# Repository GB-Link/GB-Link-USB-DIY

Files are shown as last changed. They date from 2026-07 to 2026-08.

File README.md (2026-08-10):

# GB-Link USB DIY: USB TO GAME BOY LINK ADAPTER

Board 3D Render

An Open-Source USB to Gameboy Link Cable Adapter for Raspberry Pi Pico. Designed with components that are easy to source and solder. Original design by agtbaskara. Link port footprint added by fairy0715. 
This board allows you to connect to GB/C or GBA games using a gereric GBC cable. OEM cables will work with their expected games.

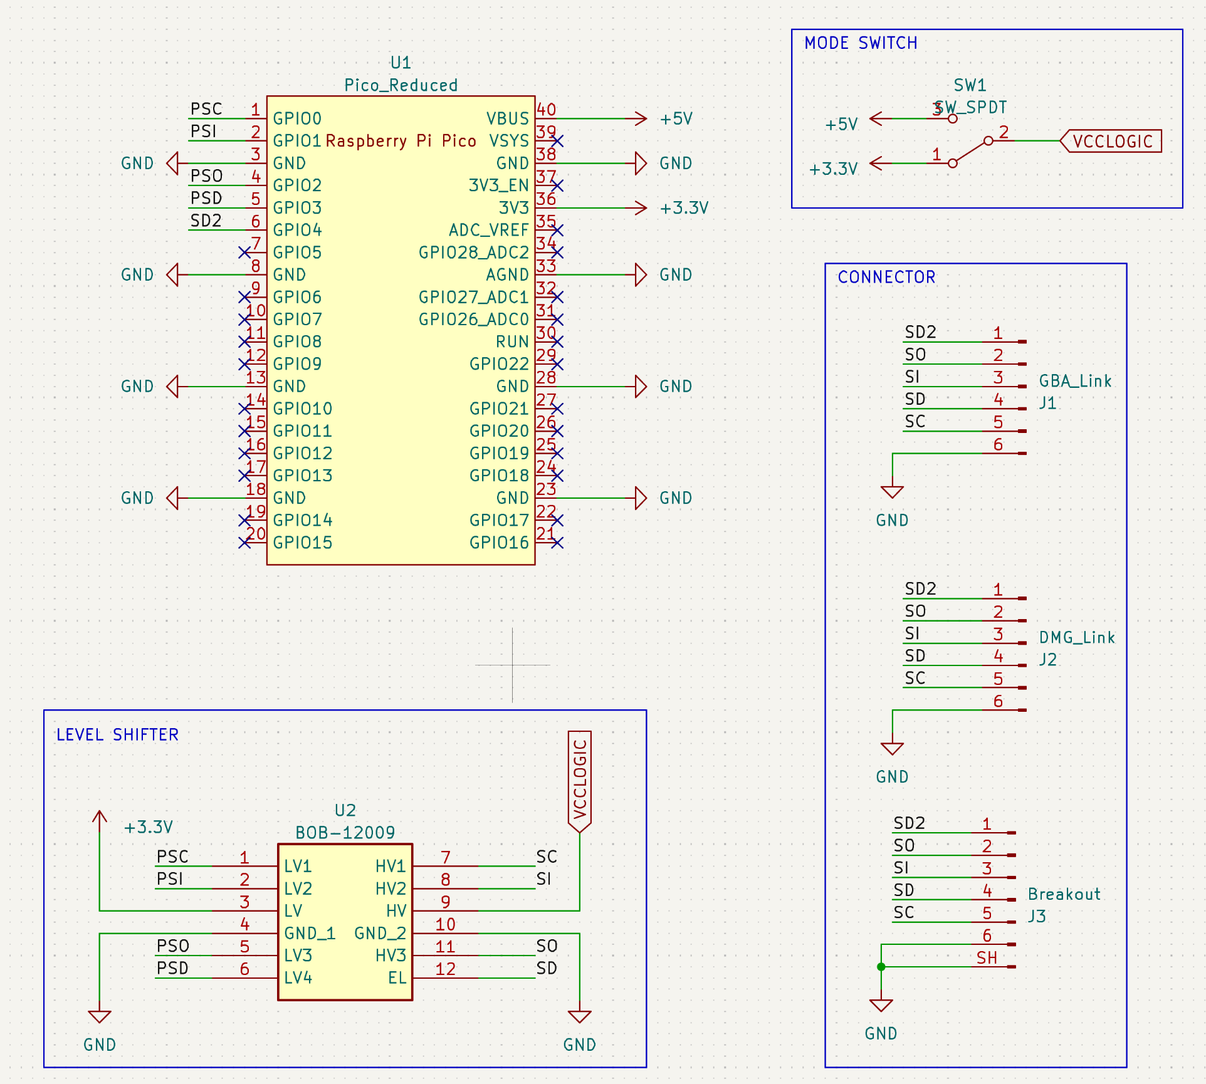
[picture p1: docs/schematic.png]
Schematic


# Required Components

| Reference | Part Number | Description |
|-|-|-|
| U1 | [Raspberry Pi Pico](https://www.raspberrypi.com/products/raspberry-pi-pico/) | Clones are compatible |
| U2 | [BOB-12009](https://www.sparkfun.com/products/12009) | Sparkfun Bi-Directional Logic Level Converter, clones are compatible |
| SW1 | [SS12D00-G3](https://www.amazon.com/Tnuocke-Vertical-Position-Switches-SS12D00-G3/dp/B099MRCDG8) | 3 Pin SPDT Switch with 1" (2.54mm) Pitch |

# Optional Case
Optional case available to print, works well in either PLA or PETG. No screws or glue needed.

https://www.printables.com/model/1805845-gb-link-v11-housing

Case-Front

Case-Back

# How to Order Board

To order a board, use the `gerbers.zip` from the release page or generate one yourself. You can order from your favourite PCB manufacturer ([JLCPCB](https://jlcpcb.com/), [PCBWay](https://www.pcbway.com/), etc.).

**Use 1.2mm PCB thickness.**

You can choose any colour for the Solder Mask and Silkscreen. For the Surface Finish, ENIG is highly recommended.

# How to Assemble Board

1. Sand the PCB edge connectors if necessary.
2. Solder pin header to Raspberry Pi Pico and Level Shifter module. Use a breadboard for easier pin soldering.
3. Solder Raspberry Pi Pico and Level Shifter module to the board
5. Solder the 1x3 Pin Header to the board, and place the Pin Jumper
6. Flash firmware to your Raspberry Pi Pico

Recomended firmware:
- [https://github.com/GB-Link/GBLink-Firmware/releases](https://github.com/GB-Link/GBLink-Firmware/releases)
List of clients for the GB-Link firmware found at [https://launcher.gblink.io/](https://launcher.gblink.io/)

Other compatible firmware:
- https://github.com/Celio-Link/Celio-Firmware
- https://github.com/Lorenzooone/pico-gb-mobile-adapter
- https://github.com/starlarkus/gb-link-firmware-reconfigurable
- https://github.com/stacksmashing/gb-link-firmware
- https://github.com/stacksmashing/gb-link-printer
- https://github.com/dj505/GBPrinterEmu
- https://github.com/Squaresweets/GBPrinter-discord-bot
- https://github.com/KuestenKeks/pc-to-gb-printer

- Raspberry Pi Pico Footprint: https://github.com/ncarandini/KiCad-RP-Pico
- Logic Level Converter (BOB-12009) Footprint: https://www.snapeda.com/parts/BOB-12009/SparkFun%20Electronics/view-part/
- Gameboy Link Connector Footprint: https://github.com/Palmr/gb-link-cable
- 1.2mm PCB Thickness, based on: https://hackaday.io/project/12932-game-link-online/log/43999-received-the-breakout-boards

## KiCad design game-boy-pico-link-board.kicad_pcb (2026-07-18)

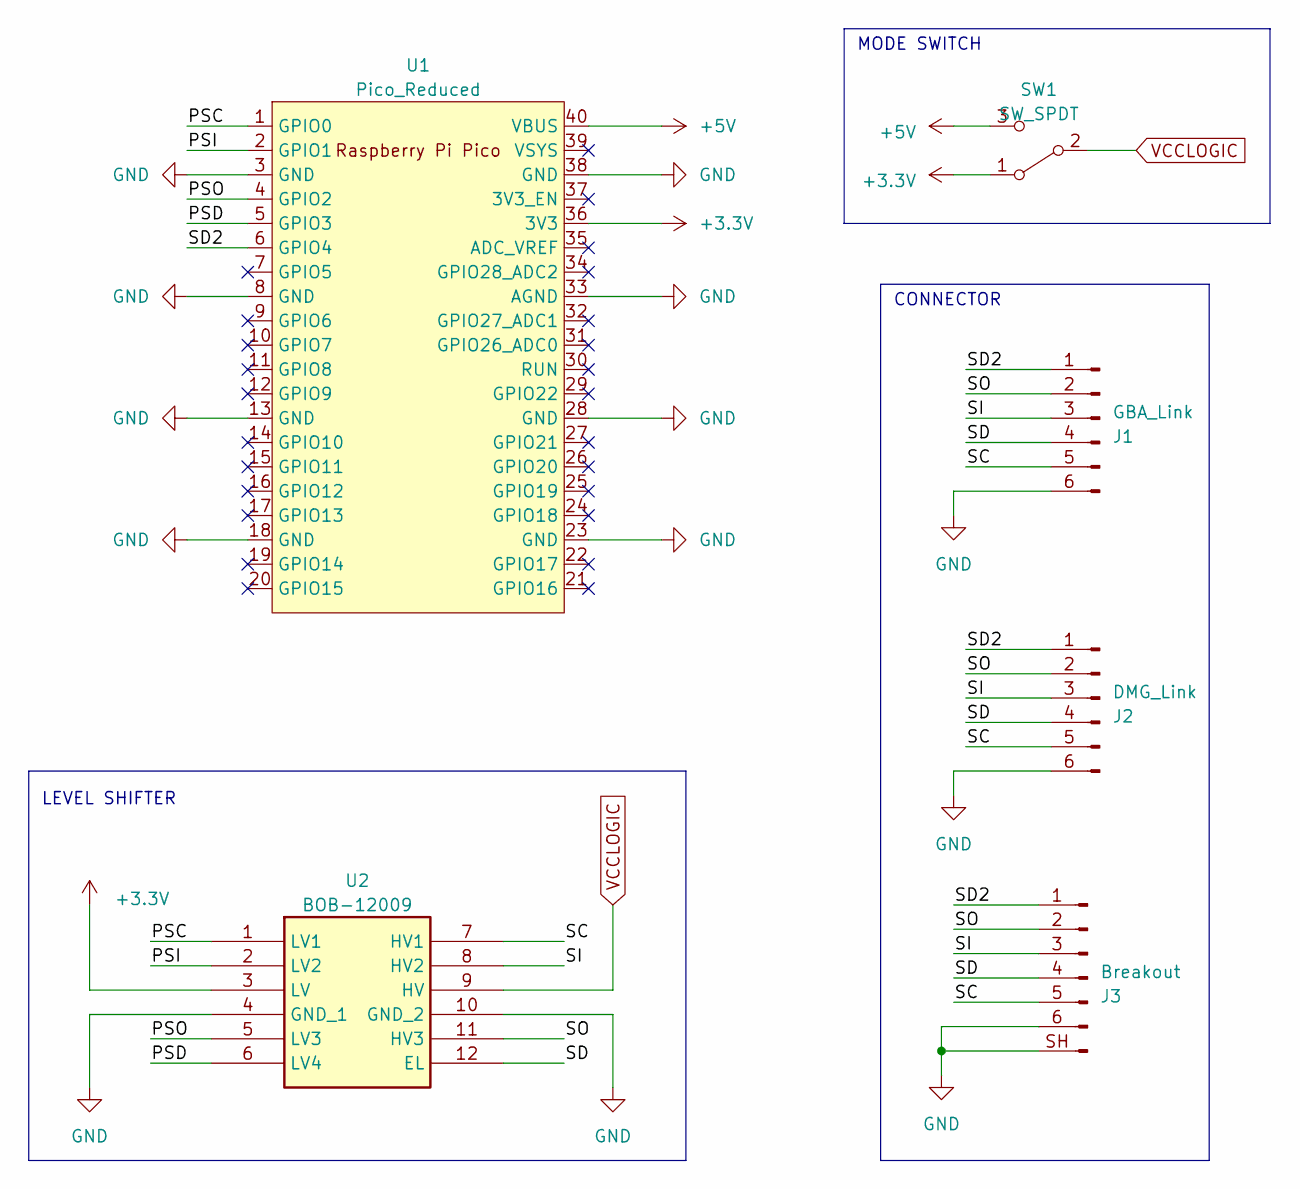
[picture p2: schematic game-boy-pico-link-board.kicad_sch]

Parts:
J1: GBA_Link; gb-link-socket
J2: DMG_Link; dmg-link-socket
J3: Breakout; gba_linkport
SW1: SW_SPDT; PinHeader_1x03_P2.54mm_Vertical
U1: Pico_Reduced; RPi_Pico_SMD_TH_REDUCED
U2: BOB-12009

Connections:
+3.3V: SW1.1 (A), U1.36 (3V3), U2.3 (LV)
+5V: SW1.3 (C), U1.40 (VBUS)
/GBVCC: J1.1, J2.1, J3.1, U1.6 (GPIO4)
/PSC: U1.1 (GPIO0), U2.1 (LV1)
/PSD: U1.5 (GPIO3), U2.6 (LV4)
/PSI: U1.2 (GPIO1), U2.2 (LV2)
/PSO: U1.4 (GPIO2), U2.5 (LV3)
/SC: J1.5, J2.5, J3.5, U2.7 (HV1)
/SD: J1.4, J2.4, J3.4, U2.12 (EL)
/SI: J1.3, J2.3, J3.3, U2.8 (HV2)
/SO: J1.2, J2.2, J3.2, U2.11 (HV3)
GND: J1.6, J2.6, J3.6, J3.SH (Pin_7), U1.3 (GND), U1.8 (GND), U1.13 (GND), U1.18 (GND), U1.23 (GND), U1.28 (GND), U1.33 (AGND), U1.38 (GND), U2.4 (GND_1), U2.10 (GND_2)
VCCLOGIC: SW1.2 (B), U2.9 (HV)

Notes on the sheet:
LEVEL SHIFTER
MODE SWITCH
CONNECTOR

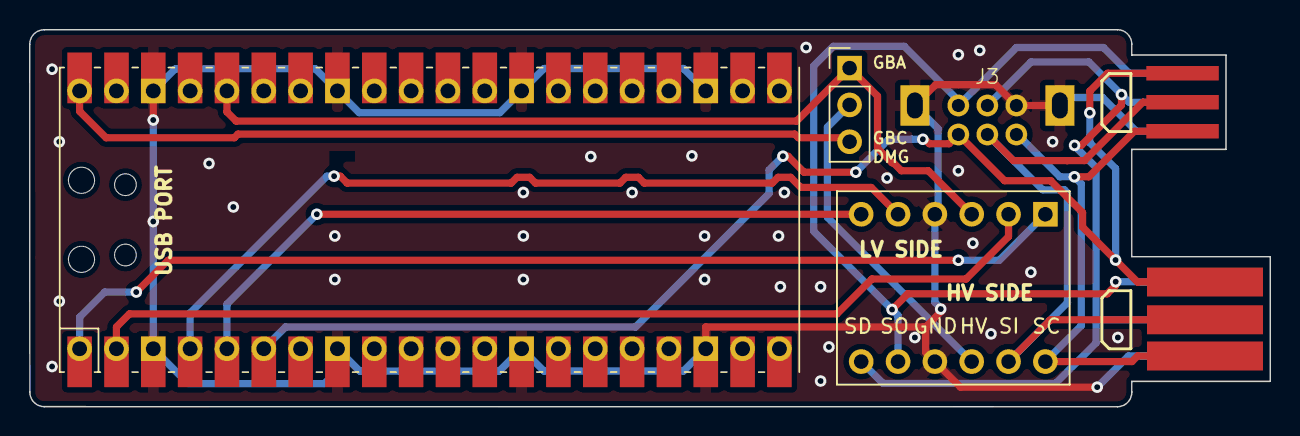
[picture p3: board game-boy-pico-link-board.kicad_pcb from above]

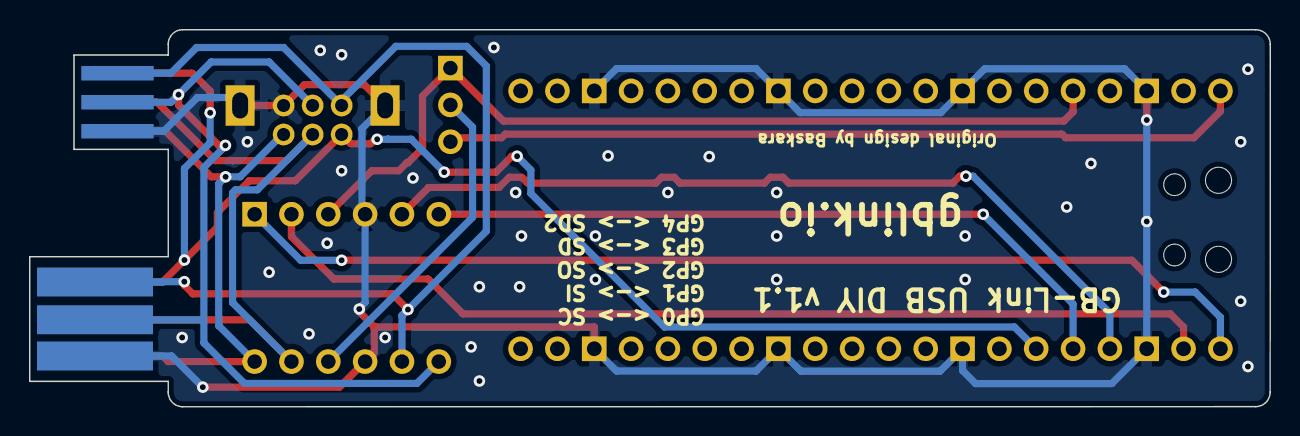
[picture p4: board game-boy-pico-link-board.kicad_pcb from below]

Board: 2 copper layers, 85.5 x 26.0 mm, 6 parts (2 on the bottom side), 13 nets.

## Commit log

2026-06-11 readmeを修正
2026-07-18 Clarify PCB surface finish and assembly steps
    Updated recommendations for PCB surface finish and assembly instructions.
2026-07-18 Add SD2 for link cable detection
    Adds SD2 using GP4 for GBA communication over a GBC link cable
    [game-boy-pico-link-board.kicad_pcb, game-boy-pico-link-board.kicad_sch]
2026-07-18 Update README with design attribution and details
    Added attribution to original design and clarified cable compatibility.
2026-08-10 Add optional case details to README
    Added information about an optional case for printing.
2026-08-10 Update README with case images
    Added images for case
